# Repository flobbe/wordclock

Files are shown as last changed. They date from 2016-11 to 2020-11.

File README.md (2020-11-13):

# Flo's word clock

This is my DIY version of a word clock, which shows the time as it is spoken.
It consists of 143 LEDs (13 x 11) behind a predefined letter layout.

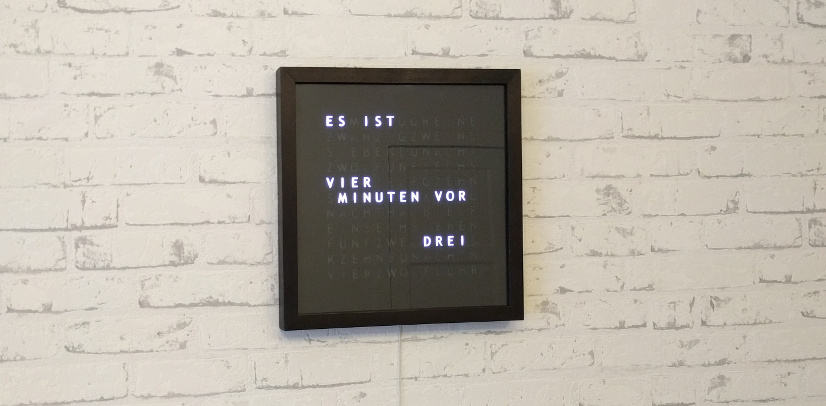
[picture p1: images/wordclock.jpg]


Unlike many other word clock implementations it can express every minute of the day (not just every fifth).

## Parts list

I used the following components:

 - 143 WS2812B LEDs on a strip with 60 LEDs/meter, so you need 3 meters
 - 5 V Power supply with about 8 A output current (I used a [MeanWell LPV-60-5](https://www.meanwell-web.com/en-gb/ac-dc-single-output-led-driver-constant-voltage-cv-lpv--60--5))
   - each of the 143 LEDs can draw about 50-60 mA (but normally the total consumption is below 500mA)
 - DOIT ESP32 DEVKIT V1 microcontroller board
 - 3.3V to 5V logic level converter
 - Picture frame that can hold 30 x 30 x 1.5 cm
 - 3D printed socket for the LEDs, see below
 - frosted acrylic glass (3 mm) to diffuse the light (alternatively semi-transparent paper will also work)
 - The letter matrix made of black cardboard cut out by laser, see below

## 3D printed socket for the LED strips

You will find the [OpenSCAD](https://www.openscad.org/) model (and also a generated .stl file) to hold the LED strips in place in the 3d-print folder:
[wordclock_led_boxes.scad](./3d-print/wordclock_led_boxes.scad)

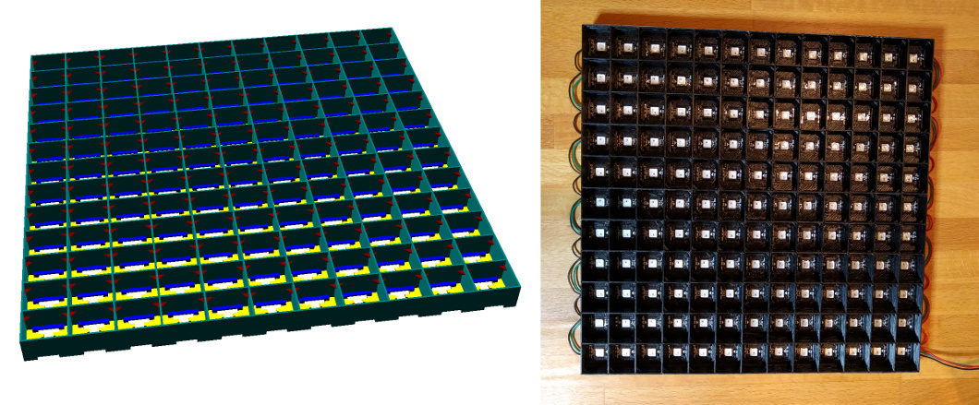
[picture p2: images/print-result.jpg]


## Laser cut layout

For the letter layout there is a [.svg file](./letter-layout/layout-13x11-path.svg).
This has to be cut out of a 30 cm x 30 cm piece of cardboard.

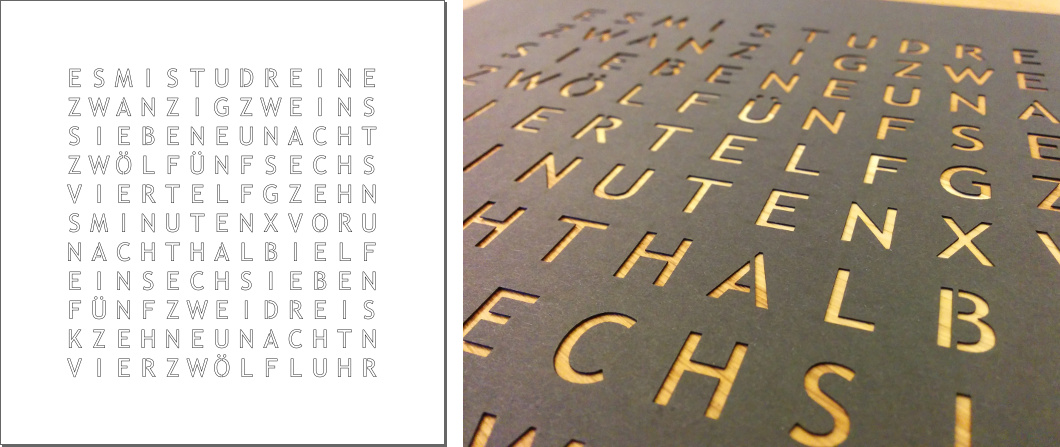
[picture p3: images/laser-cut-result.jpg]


## Light scattering

For an even illumination of each letter I used a 3 mm frosted acrylic glass,
which I cut into small pieces 15.7 mm x 18.5 mm each, to fit into the 3D printed LED socket.

## Software compilation

### Prepare IDE for ESP32

 1. Install and run Arduino IDE _(version >= 1.8.8)_
 2. Add "Additional Boards Manager URL" (in menu: "File -> Preferences"):  
     `https://dl.espressif.com/dl/package_esp32_index.json`
 3. Install via "Boards Manager" (in menu: "Tools -> Boards"):  
     - `esp32`              by `Espressif Systems` _(version >= 1.0.0)_  
     - `Arduino AVR Boards` by `Arduino`           _(version >= 1.6.23)_
 4. Select Board: `DOIT ESP32 DEVKIT V1`

### Used libraries

The following software libraries are used and can be installed via the Arduino IDE "Library Manager":

 - `NeoPixelBus` by `Makuna`         _(version >= 2.4.1)_
 - `MQTT`        by `Joel Gaehwiler` _(version >= 2.4.1)_

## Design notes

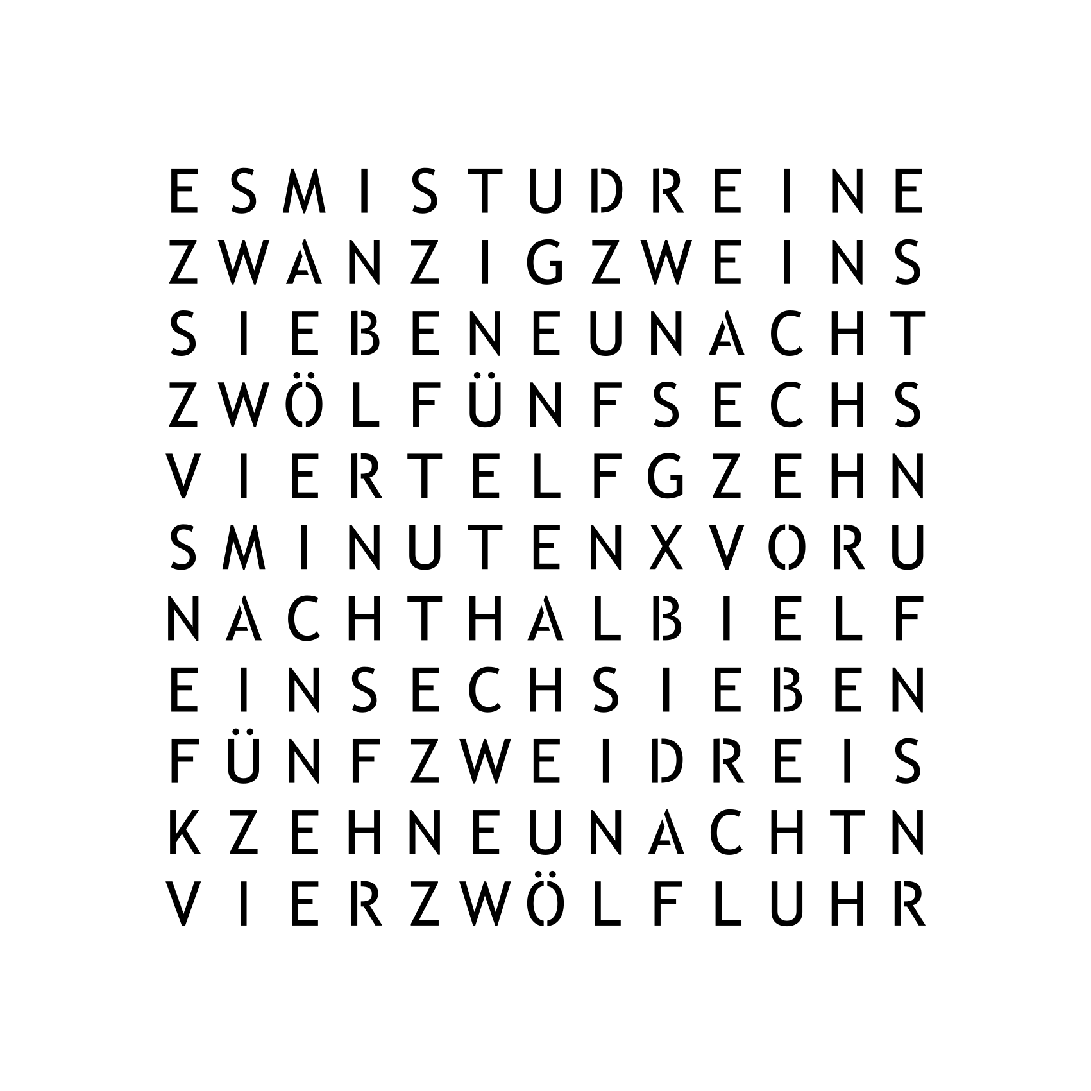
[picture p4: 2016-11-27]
letter-layout/layout-13x11-raster.png

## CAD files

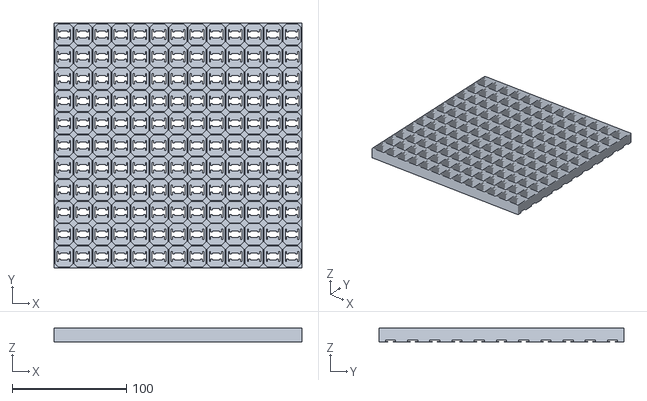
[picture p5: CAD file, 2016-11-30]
3d-print/wordclock_led_boxes.stl
217.1 x 214.6 x 12.5

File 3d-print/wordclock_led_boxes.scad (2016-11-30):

//
//  Model to hold WS2812 LED strips so that each LED illuminates only one letter of the word clock.
//

//               [mm]
// teal box
box_width      = 16.6+0.04;
box_height     = 19.4+0.04;
box_depth      = 12.5;
wall_thickness = 0.8;
// yellow base plate / led holder
base_thickness = 0.7;
// corner pod (maroon)
pod_corner     = 3;
pod_z          = box_depth - 3.4;
// spaces
led_size       = 5+1;
resistor_size  = 4;
// gap for solder between leds
solder_width   = 9;    // y
solder_length  = wall_thickness+6;  // x
solder_height  = 1.7;  // z
// cutter thickness
cutter         = 0.15;

$fs = 0.1;
$fa = 1;

module corner(trans, rot) {
    translate(trans)
        rotate(rot)
            polyhedron(
                points=[[0,0,0], [pod_corner,0,0], [0,pod_corner,0], [0,0,-pod_corner]],
                faces=[[0,1,2], [1,3,2], [0,2,3], [0,3,1]]
            );
}

module box(top=true, right=true, bottom=true, left=true) {
    wt = wall_thickness;
    bt = base_thickness;
    o = 0.1; // erode box when building difference
    translate([(box_width+wt)/2, (box_height+wt)/2, 0]) {
        difference() {
            union() {
                difference() {      
                    union() {
                        color("Teal") {
                            translate([0, 0, box_depth/2])
                                difference() {      
                                    cube([box_width+wt, box_height+wt, box_depth],   center=true);
                                    cube([box_width-wt, box_height-wt, box_depth+1], center=true);
                                } // difference
                        } // color: Teal
                        color("Yellow") {
                            translate([0, 0, bt/2]) {
                                cube([box_width-wt, box_height-wt, bt], center=true);
                            }
                        } // color: Yellow
                        color("Blue") {
                            w = 1.9;  // width of the "solder roof"
                            s = wt+1.4; // size of the bridge pier
                            translate([(box_width-wt-w)/2, 0, solder_height/2+bt])
                                cube([w, solder_width+2*s, solder_height], center=true);
                            translate([-(box_width-wt-w)/2, 0, solder_height/2+bt])
                                cube([w, solder_width+2*s, solder_height], center=true);
                        } // color: Blue
                    } // union
                    if (! top)
                        translate([0,  (box_height-cutter+o)/2, box_depth/2])
                            cube([box_width+wt+o,  wt+cutter+o, box_depth+o], center=true);
                    if (! bottom)
                        translate([0, -(box_height-cutter+o)/2, box_depth/2])
                            cube([box_width+wt+o,  wt+cutter+o, box_depth+o], center=true);
                    if (! left)
                        translate([-(box_width-cutter+o)/2, 0,  box_depth/2])
                            cube([wt+cutter+o, box_height+wt+o, box_depth+o], center=true);
                    if (! right)
                        translate([ (box_width-cutter+o)/2, 0,  box_depth/2])
                            cube([wt+cutter+o, box_height+wt+o, box_depth+o], center=true);
                } // difference
                color("Maroon") {
                    t = top    ? 0 : cutter;
                    r = right  ? 0 : cutter;
                    b = bottom ? 0 : cutter;
                    l = left   ? 0 : cutter;
                    corner([ (wt-box_width)/2+l,  (wt-box_height)/2+b, pod_z], [0, 0,   0]);
                    corner([-(wt-box_width)/2-r,  (wt-box_height)/2+b, pod_z], [0, 0,  90]);
                    corner([-(wt-box_width)/2-r, -(wt-box_height)/2-t, pod_z], [0, 0, 180]);
                    corner([ (wt-box_width)/2+l, -(wt-box_height)/2-t, pod_z], [0, 0, 270]);
                } // color: Maroon
            } // union
            color("Gray") {
                translate([0, 0, bt/2]) {
                    cube([led_size, led_size, bt+o], center=true);
                    cube([box_width, resistor_size, bt+o], center=true);
                }
                gap_x = solder_length;
                translate([ (box_width)/2, 0, (solder_height-o/2)/2])
                    cube([gap_x, solder_width, solder_height+o/2], center=true);
                translate([-(box_width)/2, 0, (solder_height-o/2)/2])
                    cube([gap_x, solder_width, solder_height+o/2], center=true);
            } // color: Gray
        } // difference
    } // translate
}


// ===== create all boxes =====
for (y = [1:11], x = [1:13])
    translate([(x-1) * box_width, (y-1) * box_height, 0])
        box();


// ===== OR, if your printer is not large enough, print it in parts =====
/*
parts = [1,2,3,4];  // select one of the four parts here to render and export separately

module __() {                    }  // empty element, to make spreadElems() over all childrens work
module b_() { box();             }  // normal box
module bt() { box(top=false);    }  // box without top wall
module bb() { box(bottom=false); }  // box without bottom wall
module bl() { box(left=false);   }  // box without left wall
module br() { box(right=false);  }  // box without right wall
module spreadElems(dx=0, dy=0) {
    for (i = [0:1:$children-1])   // step=1 needed in case $children < 2
        translate([i * dx, i * dy, 0])
            children(i);
}

for (p = parts) {
    if (p == 1) {
        translate([0, -box_height, 0])
            spreadElems(0, -box_height) {
                spreadElems(box_width, 0) { b_();b_();b_();b_();b_();br();      }
                spreadElems(box_width, 0) { b_();b_();b_();b_();b_();b_();br(); }
                spreadElems(box_width, 0) { b_();b_();b_();b_();b_();b_();br(); }
                spreadElems(box_width, 0) { b_();b_();b_();b_();b_();br();      }
                spreadElems(box_width, 0) { b_();b_();bb();bb();b_();br();      }
                spreadElems(box_width, 0) { bb();bb();__();__();bb();bb();br(); }
            }
    }
    if (p == 2) {
        translate([6*box_width, -box_height, 0])
            spreadElems(0, -box_height) {
                spreadElems(box_width, 0) { bb();b_();b_();b_();b_();b_();b_(); }
                spreadElems(box_width, 0) { __();b_();b_();b_();b_();b_();b_(); }
                spreadElems(box_width, 0) { __();b_();b_();b_();b_();b_();b_(); }
                spreadElems(box_width, 0) { bt();b_();b_();b_();b_();b_();b_(); }
                spreadElems(box_width, 0) { bb();bb();bb();b_();b_();bb();bb(); }
                spreadElems(box_width, 0) { __();__();__();bb();bb();           }
            }
    }
    if (p == 3) {
        translate([0, 6*-box_height, 0])
            spreadElems(0, -box_height) {
                spreadElems(box_width, 0) { __();__();bl();br();                }
                spreadElems(box_width, 0) { b_();b_();b_();b_();b_();br();      }
                spreadElems(box_width, 0) { b_();b_();b_();b_();b_();br();      }
                spreadElems(box_width, 0) { b_();b_();b_();b_();b_();b_();br(); }
                spreadElems(box_width, 0) { b_();b_();b_();b_();b_();b_();br(); }
                spreadElems(box_width, 0) { b_();b_();b_();b_();b_();br();      }
                }
    }
    if (p == 4) {
        translate([6*box_width, 6*-box_height, 0])
            spreadElems(0, -box_height) {
                spreadElems(box_width, 0) { __();b_();br();__();__();bl();b_(); }
                spreadElems(box_width, 0) { bt();b_();b_();b_();b_();b_();b_(); }
                spreadElems(box_width, 0) { bb();b_();b_();b_();b_();b_();b_(); }
                spreadElems(box_width, 0) { __();b_();b_();b_();b_();b_();b_(); }
                spreadElems(box_width, 0) { __();b_();b_();b_();b_();b_();b_(); }
                spreadElems(box_width, 0) { bt();b_();b_();b_();b_();b_();b_(); }
                }
    }
}
//*/
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

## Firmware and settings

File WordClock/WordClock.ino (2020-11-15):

// -*- mode: c -*-

#if defined(ESP32)
    #include <WiFi.h>
    #include <ESPmDNS.h>
#elif defined(ESP8266)
    #include <ESP8266WiFi.h>
    #include <ESP8266mDNS.h>
    #include <DNSServer.h>
#else
    #error Only tested with ESP32. OTA and telnet debugging require wifi, so the esp8266 may work as well. I have no idea about other devices.
#endif

#include <WiFiUdp.h>
#include <ArduinoOTA.h>
#include <time.h>

#include "configuration.h"
#include "LedMatrix.h"

#if MQTT_ENABLED
    #include <MQTT.h>  // "MQTT" by Joel Gaehwiler (v2.4.1) -- https://github.com/256dpi/arduino-mqtt
#endif



// --------------------------------------------------

uint32_t gProcessTimeMainLoop;
uint32_t gProcessTimeTaskLoop;

time_t    previous_time = 0;

time_t    last_sync_time;  // last time, system time was updated from ntp server

LedMatrix led_matrix;

#if MQTT_ENABLED
    WiFiClient network;
    MQTTClient mqttClient;
    TaskHandle_t taskmqtt;
#endif

// --------------------------------------------------

#define LOG_PRINTFLN(fmt, ...)  printfln_P(PSTR(fmt), ##__VA_ARGS__)
#define LOG_SIZE_MAX 256
void printfln_P(const char *fmt, ...)
{
    char buf[LOG_SIZE_MAX];
    va_list ap;
    va_start(ap, fmt);
    vsnprintf_P(buf, LOG_SIZE_MAX, fmt, ap);
    va_end(ap);
    Serial.println(buf);
#if MQTT_ENABLED
    mqttClient.publish("tele/" THIS_HOST_NAME "/LOG", buf);
#endif
}

// --------------------------------------------------

void initWiFi()
{
    Serial.printf("Connecting to WiFi %s ", WIFI_SSID);
    WiFi.mode(WIFI_STA);
    WiFi.begin(WIFI_SSID, WIFI_PASSWORD);
    uint8_t timeout = 20; // seconds
    while (WiFi.status() != WL_CONNECTED && timeout > 0)
    {
        delay(1000);
        Serial.printf(".");
        timeout--;
    }
    if (timeout > 0)
    {
      Serial.println(" done");
      LOG_PRINTFLN("Connected to WiFi");
      LOG_PRINTFLN("IP address: %s", WiFi.localIP().toString().c_str());
    }
    else
    {
      Serial.println(" FAILED!");
      led_matrix.showWifiError();
      while (true) { delay(1000); }
    }
}

void getNTPTime()
{
    // request time from ntp server
    configTime(0, 0, TIME_NTP_SERVER);
    setenv("TZ", TIME_POSIX_TIMEZONE_STR, 1);
    tzset();

    // check validity of local time
    struct tm timeinfo;
    if (getLocalTime(&timeinfo))
    {
      LOG_PRINTFLN("received ntp time");
      time(&last_sync_time);
    }
    else
    {
      LOG_PRINTFLN("ERROR: Could not determine the time! Make sure the ntp server is accessible (check wifi and dns).");
      // TODO: set led_matrix to error screen
    }
}

void initOTA()
{
    ArduinoOTA.setHostname(THIS_HOST_NAME);
    ArduinoOTA.onStart([]()
                {
#if MQTT_ENABLED
                    vTaskSuspend(taskmqtt);
#endif
                })
              .onEnd([]()
                {
                    ESP.restart();
                })
              .onProgress([](unsigned int progress, unsigned int total)
                {
                    static uint8_t lastPercent = 100;
                    uint8_t percent = progress / (total / 100);
                    led_matrix.setUpdateProgress(progress, total);
                    if (percent != lastPercent)
                    {
                        Serial.printf("Progress: %u / %u = %u %%\r", progress, total, percent);
                        lastPercent = percent;
                    }
                })
              .onError([](ota_error_t error)
                {
                    if (error == OTA_AUTH_ERROR)         LOG_PRINTFLN("OTAError[%u]: Auth Failed",    error);
                    else if (error == OTA_BEGIN_ERROR)   LOG_PRINTFLN("OTAError[%u]: Begin Failed",   error);
                    else if (error == OTA_CONNECT_ERROR) LOG_PRINTFLN("OTAError[%u]: Connect Failed", error);
                    else if (error == OTA_RECEIVE_ERROR) LOG_PRINTFLN("OTAError[%u]: Receive Failed", error);
                    else if (error == OTA_END_ERROR)     LOG_PRINTFLN("OTAError[%u]: End Failed",     error);
                });
    ArduinoOTA.begin();
}


// the setup routine
void setup()
{
    Serial.begin(115200);

    //          Task function and name, Stack size in bytes, Input Parameters, Priority, Task handle.
    xTaskCreate(taskLED, "LED Task", 10000, NULL, 2, NULL);

    initWiFi();

    getNTPTime();

    xTaskCreate(taskOTA, "OTA Task", 10000, NULL, 1, NULL);

#if MQTT_ENABLED
    xTaskCreate(taskMQTT, "MQTT Task", 10000, NULL, 1, &taskmqtt);
#endif
}


// the main loop
void loop()
{
    uint32_t timeBeginLoop = millis();  // for main loop watchdog

    time_t now;

#if TIME_SIMULATION
    delay(1000 / TIME_SIMULATION_FACTOR);
    now = previous_time + 1;
#else
    time(&now);  // get system time (seconds since 1970-01-01)

    if (now - last_sync_time > TIME_SYNC_INTERVAL_SEC)
    {
        getNTPTime();
    }
#endif

    if (now != previous_time)  // update only if time (seconds) has changed
    {
        previous_time = now;

        struct tm *timeinfo = localtime(&now);

        // only print on minute changes
        if (timeinfo->tm_sec == 0)
        {
            LOG_PRINTFLN("%4d-%02d-%02d %02d:%02d:%02d   dst=%d   looptime=%lu ms",
                       timeinfo->tm_year+1900, timeinfo->tm_mon+1, timeinfo->tm_mday,
                       timeinfo->tm_hour, timeinfo->tm_min, timeinfo->tm_sec, timeinfo->tm_isdst,
                       gProcessTimeTaskLoop);
        }

        led_matrix.setTime(timeinfo->tm_hour, timeinfo->tm_min, timeinfo->tm_sec);
    }

    // main loop watchdog
    gProcessTimeMainLoop = (millis() - timeBeginLoop);
}


void taskLED(void* parameter)
{
    led_matrix.setup();
    
    while (true)
    {
        uint32_t timeBeginLoop = millis();

        led_matrix.update();
        vTaskDelay(1);

        gProcessTimeTaskLoop = (millis() - timeBeginLoop);
    }
}
 
void taskOTA(void* parameter)
{
    initOTA();
    while (true)
    {
        ArduinoOTA.handle();
        vTaskDelay(100);
    }
}


#if MQTT_ENABLED

void messageReceived(String &topic, String &payload)
{
    auto handleIntRequest = [&](String command, String log_name, int min_value, int max_value, void (*callback)(long)) {
        if (topic == "cmnd/" MQTT_DEVICE_ID "/" + command)
        {
            long payloadInt = payload.toInt();
            if (payloadInt >= min_value && payloadInt <= max_value)
            {
                callback(payloadInt);
                mqttClient.publish("tele/" MQTT_DEVICE_ID "/" + command, String(payloadInt));
            }
            else
                LOG_PRINTFLN("invalid argument to set %s '%s'. possible values: [%d..%d]", log_name, payload, min_value, max_value);
        }
    };

    static uint8_t r = 0, g = 0, b = 0;
    LOG_PRINTFLN("incoming: %s - %s", topic.c_str(), payload.c_str());
    handleIntRequest("restart",     "restart uC",       1,   1, [](long int_arg){ ESP.restart(); });
    handleIntRequest("brightness",  "brightness",       0, 100, [](long int_arg){ led_matrix.setBrightness(int_arg * 254 / 100 + 1); });
    handleIntRequest("color/red",   "word color red",   0, 100, [](long int_arg){ r = int_arg * 255 / 100; led_matrix.setWordColor(r, g, b); });
    handleIntRequest("color/green", "word color green", 0, 100, [](long int_arg){ g = int_arg * 255 / 100; led_matrix.setWordColor(r, g, b); });
    handleIntRequest("color/blue",  "word color blue",  0, 100, [](long int_arg){ b = int_arg * 255 / 100; led_matrix.setWordColor(r, g, b); });
    handleIntRequest("seconds",     "seconds mode",     0,   4, [](long int_arg){ led_matrix.setSecondsMode(int_arg); });
    handleIntRequest("splash",      "splash screen",    0,   1, [](long int_arg){ led_matrix.setSplashScreen(int_arg); });
}
void taskMQTT(void* parameter)
{
    mqttClient.begin(MQTT_BROKER_IP, network);
    mqttClient.onMessage(messageReceived);
    while (true)
    {
        if (!mqttClient.connected())
        {
            Serial.print("connecting to MQTT broker ... ");
            if (mqttClient.connect(THIS_HOST_NAME, MQTT_USERNAME, MQTT_PASSWORD))
            {
                Serial.println("done.");
                mqttClient.subscribe("cmnd/" MQTT_DEVICE_ID "/#"); // subscribe to all command topics for this device
            }
            else
            {
                Serial.println("FAILED!");
            }
        }
        mqttClient.loop();
        vTaskDelay(1);
    } // while (true)
}

#endif

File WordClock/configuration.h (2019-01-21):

#ifndef __CONFIGURATION_H
#define __CONFIGURATION_H


#define WIFI_SSID                 ""   // <-- insert your wifi name here
#define WIFI_PASSWORD             ""   // <-- insert yout wifi password here

#define THIS_HOST_NAME            "wordclock"

#define MQTT_ENABLED              false
#define MQTT_BROKER_IP            "192.168.5.55"
#define MQTT_USERNAME             "my-mqtt-user"
#define MQTT_PASSWORD             "my-mqtt-password"
#define MQTT_DEVICE_ID            THIS_HOST_NAME

#define TIME_NTP_SERVER           "ptbtime1.ptb.de", "ptbtime2.ptb.de", "pool.ntp.org"
#define TIME_POSIX_TIMEZONE_STR   "CET-1CEST,M3.5.0,M10.5.0/3"  // germany/berlin ; see https://www.gnu.org/software/libc/manual/html_node/TZ-Variable.html
#define TIME_SYNC_INTERVAL_SEC    5 *   60       // update system clock over ntp [in seconds]

#define TIME_SIMULATION           false          // just for development
#define TIME_SIMULATION_FACTOR    20

#define MATRIX_WIDTH              13
#define MATRIX_HEIGHT             11
#define MATRIX_LED_PIN            13
#define MATRIX_LED_CHIPSET        WS2812B
#define MATRIX_LED_COLOR_ORDER    GRB
#define MATRIX_LED_BRIGHTNESS     13           // max led brightness (0..255)


#endif  // __CONFIGURATION_H

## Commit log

2016-11-30 3D printed parts
    [wordclock_led_boxes.scad, wordclock_led_boxes.stl]
2017-12-22 first software version for teensy
    [configuration.h]
2019-01-08 Switched from Teensy with fragile DCF77 module to ESP32 with Wi-Fi and NTP client
    [configuration.h]
2019-01-21 add MQTT support
    [configuration.h]
